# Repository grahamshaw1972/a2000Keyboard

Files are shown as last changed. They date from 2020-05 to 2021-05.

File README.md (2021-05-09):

# a2000Keyboard
## Amiga 2000 Mechanical Keyboard Clone

This project aims to create an Open Source Amiga 2000 keyboard. It is based on an Amiga 2000 Cherry keyboard. 

https://deskthority.net/wiki/Commodore_Amiga_2000

The PCB was cloned by Robert ( Peepo ) Taylor and TheBrew. Robert Taylor has kindly agreed to Open Source the Gerber files which he created. 

Once Printed and built, the PCB looks like this example. This one was built using Gateron Blue Switches. 

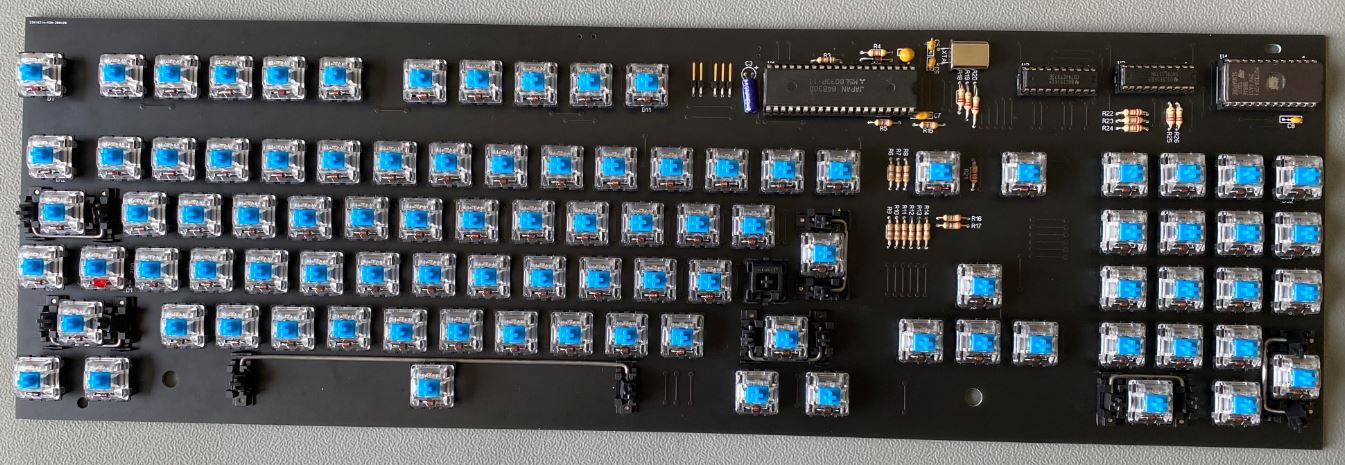
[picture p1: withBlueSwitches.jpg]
The Assembled PCB with Gateron Blue Switche


The reconstructed keyboard looks like this:

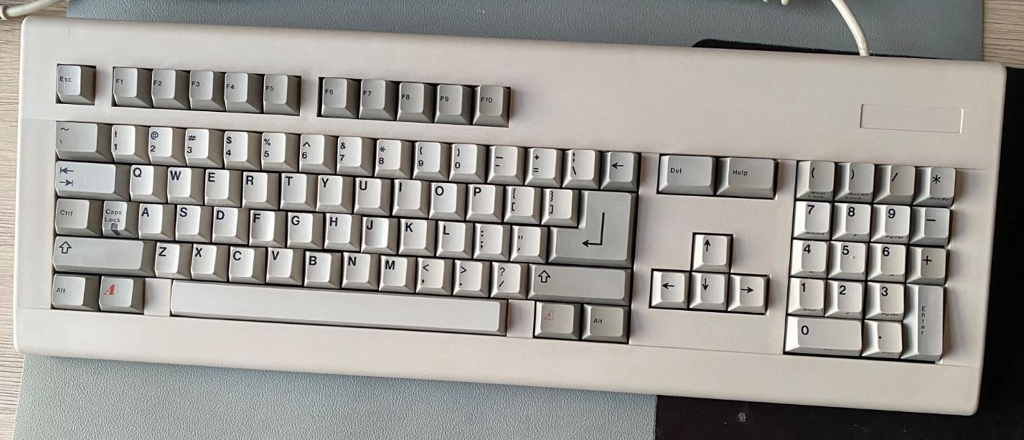
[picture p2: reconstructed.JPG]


## Repo Contents

The Gerber files for the keyboard are in the zip file: **Cherry_v2_Gerbers.zip**. These Gerber files are for a clone of the original PCB only. They will be useful to you only if you wish to replace the PCB on your existing Cherry A2000 keyboard. 

The ROM images are in the romImages directory. You will need to burn these to an EPROM using a ROM burner such as a TL866II Plus. Use Intel 2732A @DIP24 as the IC type.

a2000CherryBOM.xlsx is the Bill Of Materials for this project. If you just wish to build a new PCB to replace a damaged PCB in an existing A2000 Cherry keyboard then you will not need all of the items in the Bill Of Materials. In fact, you will likely need only items from the first tab "From Mouser". You should be able to upload the BOM to Mouser using their import BOM tool. 

https://www.mouser.co.uk/bom/

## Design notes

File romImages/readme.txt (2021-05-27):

When burning the ROM, Use Intel 2732A @DIP24 as the IC type.

Commands for assembling and disassembling:

asm48 -f bin -o rebuilt.bin a2000CherryRomAnnotated.asm

8039dasm  a2000CherryRom.BIN 2048 2048 > a2000CherryRom.asm

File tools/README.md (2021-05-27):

# Tools

Tools used in the analysis and build out of the Amiga A2000 keyboard project.

## mcs48 disassembler

This file has been aquired via https://github.com/daveho/asm48.
The only change is to print out the address that the instruction appears at.

To build on a unix box it is just a matter of typing:

```
make 8039dasm
```

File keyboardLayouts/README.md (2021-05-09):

# Keyboard Layouts
Keyboard Layout Editor was used to design the keyboard layouts for this project. It provides a simple way to design Keyboard layouts. Output files are JSON. These can be uploaded and downloaded to the website.

http://www.keyboard-layout-editor.com/

The JSON files for the keyboard layouts are located in this directory. 

a2000-cherry-keyboard-original.json - provides the layout of the original keyboard, from which the clone was created. 

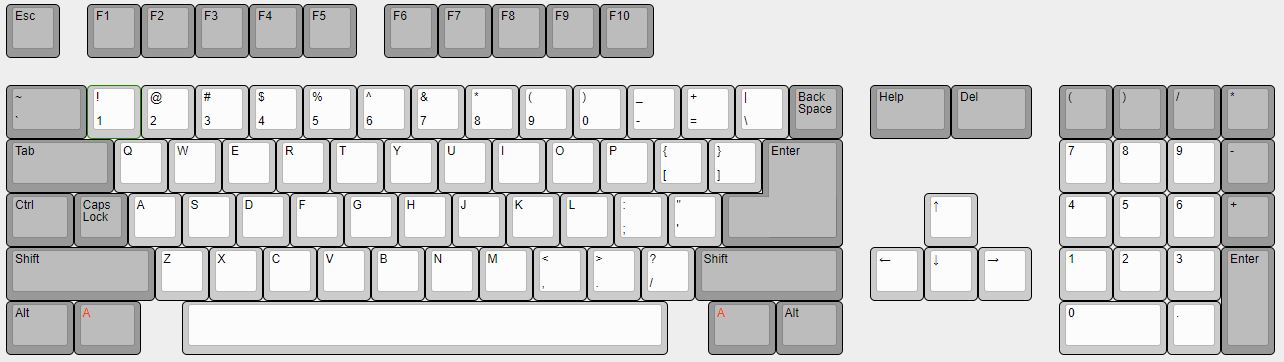
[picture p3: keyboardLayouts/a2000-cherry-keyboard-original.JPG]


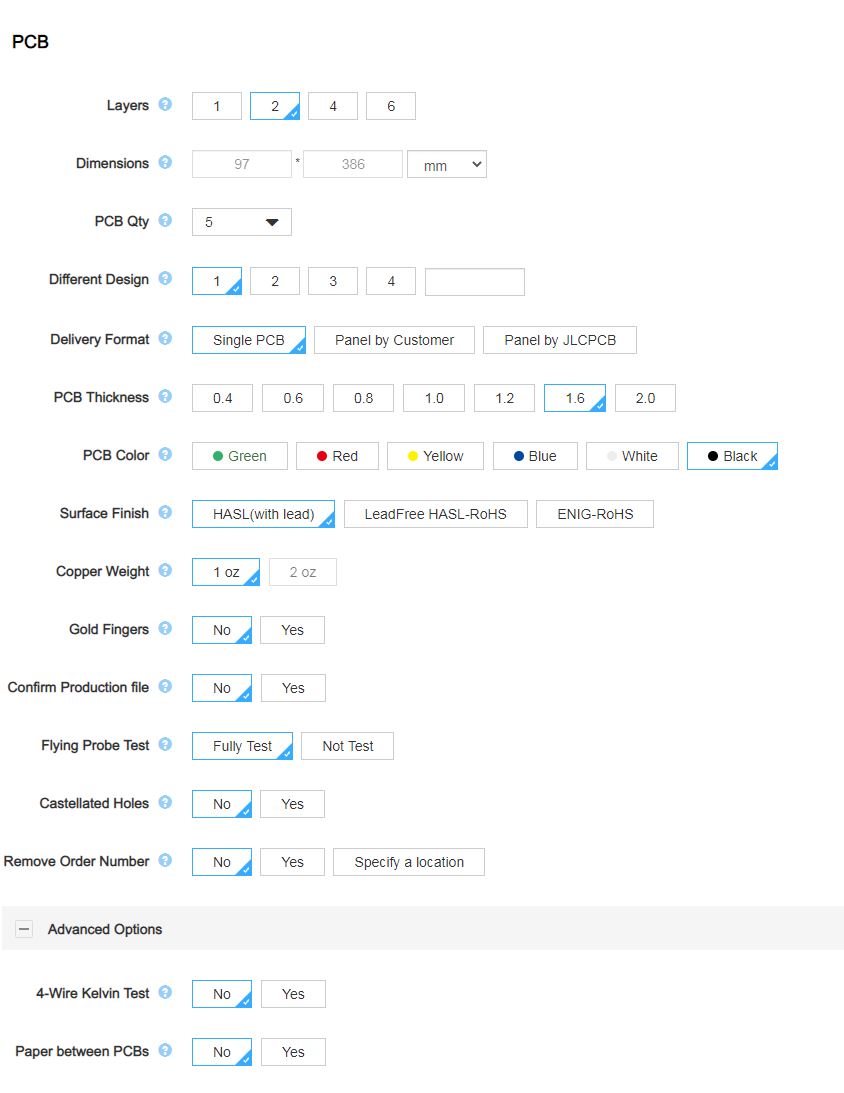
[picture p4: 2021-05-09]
keyboardLayouts/jlPcbOptions.JPG

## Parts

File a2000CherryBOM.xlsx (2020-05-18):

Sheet: From Mouser
Quantity | Mouser Part Number | References | Value | Notes
1 | 603-CFR-25JT-52-10K | R3 | 10k
1 | 603-CFR-25JT-52-47K | R4 | 47k
13 | 603-CFR-25JR-523K9 | R5, R6, R7, R8, R9, R10, R11, R12, R13, R14, R15, R16, R17 | 3.9k
8 | 603-CFR-25JT-52-22K | R18, R19, R20, R22, R23, R24, R25, R26 | 22k
1 | 603-CFR-25JT-52-2K2 | R21 | 2.2k
96 | 512-1N4148 | D52, D95, Every Switch |  | Only two required if re-using original switches
1 | 774-MP060 | XTAL | 6.00000 MHz 20pF | Crystal
1 | 581-TAP106M035SCS | C4 | 10uF | Says +10 + 35V
1 | 594-A180J15C0GH5TAA | C5 | 18 pF
1 | 80-C410C479D1G5TATU | C6 | 4.7 pF
1 | 594-A224K20X7RF5TAA | C7 | 0.22 uF
1 | 594-K104K15X7RF5TH5V | C8 | 0.1 uF
1 | 538-90121-0766 | S | Right Angle Pin Headers, 1 x 6 | Snip off pin 3 top & bottom with cutters
1 | 667-ECA-1HM100 | C3 | 10 uF | 10 uF 50V
1 | 595-CD74HCT373E | U2 | CD 74HCT373 E | Logic
1 | 595-SN74LS373N | U3 | 74LS373 PCF | Logic
2 | 517-4820-3000-CP | DIP20 Socket U2 | DIP20 Socket | Cannot use sockets if using original case. Not enough room
1 | 517-4824-6000-CP | DIP24 Socket | DIP24 Socket | Cannot use sockets if using original case. Not enough room
1 | 517-4840-6000-CP | DIP40 Socket | DIP40 Socket | Cannot use sockets if using original case. Not enough room
1 | 78-TLHK42T1U2 | Caps Lock | Red LED | Not required if re-using original switches

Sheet: Other Sources
Quantity | References | Value | Notes | URL | Alternate URL
1 | U1 | M5L8039P11 | 8 Bit Micro controller | https://www.utsource.net/itm/p/128613.html
1 | U4 | 32K EPROM | Intel 2732A | https://www.aliexpress.com/item/33024283074.html
6 |  | Cherry Screw in Stabilizer 2u |  | https://kbdfans.com/products/cherry-screw-in-stabilizer?variant=30249043132555
1 |  | Cherry Screw in Stabilizer 9u |  | ???
1 |  | 5 Pin Din Keyboard cable |  | https://amazon.co.uk/MIDI-Pin-DIN-Plug-Cable/dp/B00KEW1YZE
1 |  | Case Bottom |  | https://snijlab.nl/en
1 |  | Case Top |  | https://snijlab.nl/en
1 |  | Dupont Crimping Kit | Required for creating plug for cable | https://www.amazon.co.uk/Crimping-Ratchet-Connectors-0-1-1-0mm%C2%B2-Connector/dp/B07VC383KW
1 |  | Spade Terminal, Right Angle |  | http://dsmcz.com/prestashop/crimp-terminals/57-spade-terminal-male-48mm-pcb-right-angle-new-photo.html
1 |  | Crimp Barrel-Foil Connector |  | https://uk.rs-online.com/web/p/crimp-barrel-foil-connectors/1787178/

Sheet: Switches
Notes On Switches
The A2000 Cherry Keyboard uses Cherry MX switches. These have since become the most common switch used in Mechanical Keyboards. Most Cherry MX switches come in two different varieties, Plate mount and PCB mount. We need PCB mount for this project. That still leaves a very wide field of switches available Which switch you choose therefore comes down to personal choice.
If you choose to try and re-create the feel of the Original A2000 Cherry Keyboard, then I can provide some recommendations. The keyboard came with Cherry MX Black switches. These are one of the earliest MX switches which Cherry made. Cherry MX Black switches have changed somewhat over the years. Not in design, but in materials. Many consider that the Cherry MX Black switches of today are not as smooth feeling as those of 30 years ago. 30 year old Cherry MX Black switches are now known as Vintage Blacks to make it possible to distinguish between the two and they are quite sought after. This means that just buying Cherry MX Blacks may not re-create the original feel of the keyboard as you may expect. It's certainly an option that should be considered though.
Additionally, the A2000 Cherry Keyboard uses a different, stiffer switch for the Space Bar. This switch type is a Cherry MX Linear Grey, also known as a Cherry MX Dark Grey. In the eighties it was quite common to use a stiffer switch for the Space Bar. However, this is not so common now.
URL | Notes | Cost for 100 Switches ( in USD )
https://novelkeys.xyz/collections/switches/products/cherry-switches?variant=12495307669597 | Modern Cherry MX Black Switches | $35.00
https://novelkeys.xyz/collections/switches/products/gateron-switches?variant=19441344905309 | Gateron Cherry MX Black Clones. Cheaper and most agree that they feel very similar modern Cherry MX Blacks | $24.00
https://novelkeys.xyz/collections/switches/products/novelkeys-cream-switches | NovelKeys Cream switches. A Linear switch with a smooth feel, very similar to Vintage Cherry MX Blacks | $65.00
https://kbdfans.com/products/gateron-ink-switches | Gateron Black Ink Switches. A Linear switch with a smooth feel, very similar to Vintage Cherry MX Blacks | $75.00
NB - there are many mecanical keyboard suppliers around the world. It would probably make sense to order from one in your own country if you are able to find one.

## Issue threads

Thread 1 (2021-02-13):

ISO design and FR layout [AZERTY]

seb132, 2021-02-13:
Hello,
Great project! I'd love to help with the FR layout [AZERTY keyboard] unfortunately I believe the layout must be changed because this keyboard will have to comply with the ISO design -- which I believe contains ONE extra key and the small Return and L-Shift key...
How can we do that from your current design ?
Seb

grahamshaw1972, 2021-03-08:
Hi there seb132. Thanks for the offer of help. Yes. You are correct. In order to comply with ISO - some of the keys would need to be moved and an extra keys would indeed need to be added. The problem I have is that the original design was done by Rob Taylor. He has not had the time to update the layout. What's more, I don't had the skills with kicad to make this change myself.

grahamshaw1972, 2021-11-29:
Hey there seb132 - I have created a new A2000 keyboard. See here: https://github.com/grahamshaw1972/a2000Serotina. This one also needs a French AZERTY layout and does have a standard ISO Enter key. Please take a look.

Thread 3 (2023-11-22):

WASD Keyboards

sgerzack, 2023-11-22:
The links for the DIY kit are NG . Can you give alternative for cases .

grahamshaw1972, 2023-11-25:
Hi there, I think this issue was perhaps meant for the A2000 Serotina project instead?

sgerzack, 2023-11-25:
Yes it was my error.

On Sat, Nov 25, 2023 at 4:59 AM grahamshaw1972 ***@***.***>
wrote:

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

grahamshaw1972, 2023-11-25:
I have raised this issue myself on the A2000Serotina project. Unfortunately, I don't know of any other options. I have opened the question up to everyone. Hopefully we may get some suggestions.

sgerzack, 2023-11-26:
I ordered all the parts , a la cart . The metal backplate is no longer
listed . But was still available. On request. Time will tell if the PCB
fits the case . 🧐

On Sat, Nov 25, 2023 at 1:02 PM grahamshaw1972 ***@***.***>
wrote:

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

grahamshaw1972, 2023-11-26:
Sounds like you managed to find a case that might be okay at least. What case was it? Do you have a link to it please?

sgerzack, 2023-11-26:
WASD V3 104-Key or 105-Key Black Keyboard Case - WASD Keyboards
<https://www.wasdkeyboards.com/wasd-v3-104-key-or-105-key-black-keyboard-case.html>
This is the one I ordered . The steel backplate is the part not listed on
there web site though . I e-mailed them and they replied saying they still
had them . They sent me instructions on how to special order it . Still
waiting on delivery . Keeping my fingers crossed it all works .

On Sun, Nov 26, 2023 at 3:44 AM grahamshaw1972 ***@***.***>
wrote:

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

grahamshaw1972, 2023-11-27:
It looks the same to me. Shame they don't include a photo of the inside of the case. If they did then we could be more certain. Good luck with the build. Please feel free to email me directly: grahamshaw62@gmail.com

sgerzack, 2023-11-27:
Will do. Thanks

On Mon, Nov 27, 2023 at 2:44 AM grahamshaw1972 ***@***.***>
wrote:

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

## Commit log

2020-05-18 Initial Commit
    Containing Gerber Files, ROM Image, WASD Keycap Templates and Bill Of Materials.
    [Cherry_V2_Drills.DRL, Cherry_V2_copper_bottom.gbr, Cherry_V2_copper_top.gbr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]
2020-05-31 Include gerbers as zip only.
    [Cherry_V2_Drills.DRL, Cherry_V2_copper_bottom.gbr, Cherry_V2_copper_top.gbr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]
2020-05-31 Filled in details of how to use WASD's keycap printing service
